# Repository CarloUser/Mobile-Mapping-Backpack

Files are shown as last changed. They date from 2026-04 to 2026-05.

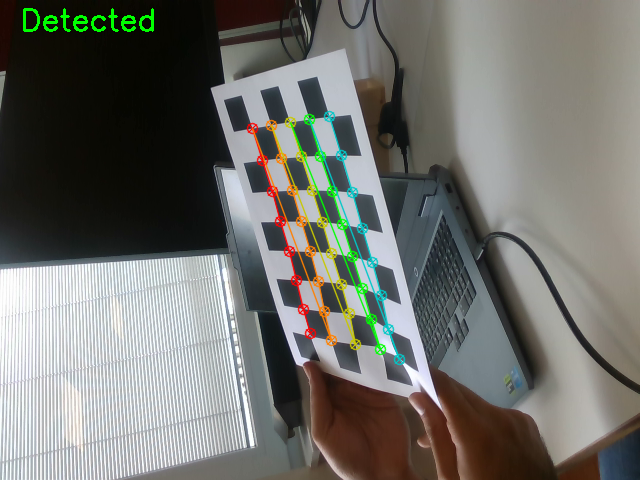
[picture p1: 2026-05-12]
opencv/calib_images/img_28.png

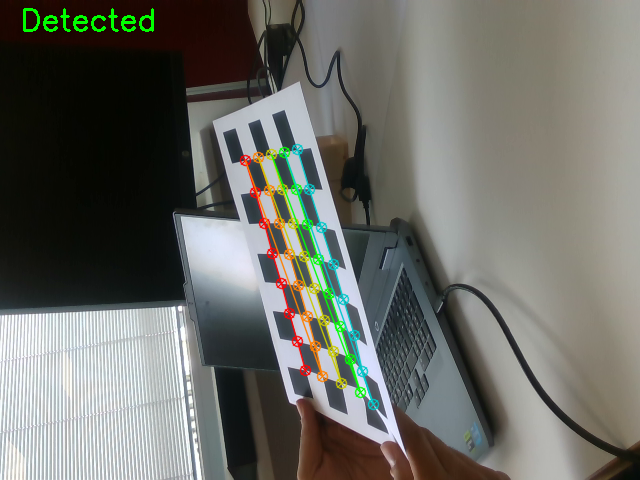
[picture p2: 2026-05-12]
opencv/calib_images/img_25.png

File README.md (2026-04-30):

# Mobile Mapping Backpack

Multi-sensor data acquisition platform integrating LiDAR, cameras, IMU, and GNSS.
Built on ROS2 Humble. Goal: synchronized, time-stamped rosbag recordings for
offline calibration validation and trajectory evaluation.

## Sensor Configuration

| Sensor | Type | Interface | ROS2 Driver |
|---|---|---|---|
| HESAI JT128 | 128-beam LiDAR | GbE | `hesai_ros_driver` |
| OAK-4D Luxonis | RGB-D + IMU | USB3 | `depthai_ros_driver` (v3) |
| OAK-D Lite Luxonis | RGB-D | USB3 | `depthai_ros_driver` |
| Intel RealSense D4xx | RGB-D | USB3 | `realsense2_camera` |
| Xsens MTi-610R | IMU | USB/RS-422 | `xsens_mti_ros2_driver` |
| u-blox + ANN-MB-00 | GNSS/RTK | USB/UART | `ublox_gps` |
| Insta360 | 360° video | Internal SD | *(no ROS2 driver — sync post-hoc)* |

## Compute

| Device | Role |
|---|---|
| NVIDIA Jetson Orin Nano S | Primary ROS2 host — runs all drivers and rosbag2 recording |
| Raspberry Pi | Auxiliary — serial bridge for IMU/GNSS if needed |

## Repository Structure

```
docs/
  setup/
    01_ros2_humble.md       ROS2 Humble installation on Jetson (Ubuntu 22.04)
    02_sensor_drivers.md    Per-sensor driver build and udev rules
    03_time_sync.md         Chrony + PTP time synchronization
  data_collection_protocol.md   Week 1 deliverable — frame IDs, topic names, recording procedure

ros2_ws/src/mmb_bringup/
  launch/
    all_sensors.launch.py   Master launch — brings up every sensor driver
    lidar.launch.py
    cameras.launch.py
    imu_gnss.launch.py
    recording.launch.py     Starts rosbag2 with MCAP storage
  config/
    hesai_jt128.yaml        Hesai driver parameters
    topics.yaml             Topic list for recording

evaluation/
  evo_workflow.md           ATE/RPE evaluation with the evo toolkit
```

## Quick Start

```bash
# 1. Check Ubuntu version — must be 22.04 for Humble
lsb_release -a

# 2. Install ROS2 Humble
# Follow docs/setup/01_ros2_humble.md

# 3. Install sensor drivers
# Follow docs/setup/02_sensor_drivers.md

# 4. Build the bringup package
cd ros2_ws && colcon build --symlink-install
source install/setup.bash

# 5. Launch all sensors
ros2 launch mmb_bringup all_sensors.launch.py

# 6. Start recording (separate terminal)
ros2 launch mmb_bringup recording.launch.py bag_name:=mmb_20260101_1200_hallway_run01
```

## Team

| Student | Role |
|---|---|
| 1 | Camera Calibration Lead |
| 2 | LiDAR Calibration Lead |
| 3 | GNSS-IMU Calibration Lead |
| 4 | Extrinsic Calibration Integrator |
| 5 | CAD Design Lead |
| 6 | System Integration & Testing Lead |

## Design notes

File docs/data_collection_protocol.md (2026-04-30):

# Data Collection Protocol

**Version**: 1.0  
**Owner**: Student 6 — System Integration & Testing Lead  
**Status**: Draft (circulate to team by end of Week 1 for review)

This document defines the naming conventions, frame IDs, topic structure,
recording procedure, and calibration sequences that all team members must
follow to ensure rosbags are interoperable across calibration workflows.

---

## 1. Coordinate Frames and TF Tree

All frames follow the ROS [REP-103](https://www.ros.org/reps/rep-0103.html)
convention: x-forward, y-left, z-up for body frames; ENU for world frames.

```
base_link                    ← physical center of the backpack frame
├── lidar_hesai              ← HESAI JT128 optical center
├── camera_oak4d             ← OAK-4D Luxonis left camera optical center
├── camera_oakd_lite         ← OAK-D Lite left camera optical center
├── camera_realsense         ← Intel RealSense color camera optical center
├── imu_xsens                ← Xsens MTi-610R measurement frame
└── gnss_antenna             ← u-blox ANN-MB-00 antenna phase center
```

**Static transforms** are published at launch from `base_link` to each sensor
frame using estimated poses from Student 5's CAD model. These are placeholders
until Student 4 delivers calibrated extrinsics; update `all_sensors.launch.py`
with the refined values in Week 2.

**Frame IDs used in sensor driver configs**:

| Sensor | `frame_id` |
|---|---|
| HESAI JT128 | `lidar_hesai` |
| OAK-4D (RGB) | `camera_oak4d` |
| OAK-D Lite (RGB) | `camera_oakd_lite` |
| Intel RealSense (color) | `camera_realsense` |
| Xsens MTi-610R | `imu_xsens` |
| u-blox GNSS | `gnss_antenna` |

---

## 2. Topic Naming Convention

All sensor topics live under a sensor-specific namespace:

| Topic | Message Type | Hz (approx) |
|---|---|---|
| `/lidar/points` | `sensor_msgs/PointCloud2` | 10 |
| `/oak4d/rgb/image_raw` | `sensor_msgs/Image` | 30 |
| `/oak4d/depth/image_raw` | `sensor_msgs/Image` | 30 |
| `/oak4d/rgb/camera_info` | `sensor_msgs/CameraInfo` | 30 |
| `/oak4d/imu/data` | `sensor_msgs/Imu` | 500 |
| `/oakd_lite/rgb/image_raw` | `sensor_msgs/Image` | 30 |
| `/oakd_lite/depth/image_raw` | `sensor_msgs/Image` | 30 |
| `/oakd_lite/rgb/camera_info` | `sensor_msgs/CameraInfo` | 30 |
| `/realsense/color/image_raw` | `sensor_msgs/Image` | 30 |
| `/realsense/depth/image_rect_raw` | `sensor_msgs/Image` | 30 |
| `/realsense/color/camera_info` | `sensor_msgs/CameraInfo` | 30 |
| `/imu/data` | `sensor_msgs/Imu` | 400 |
| `/imu/mag` | `sensor_msgs/MagneticField` | 100 |
| `/gnss/fix` | `sensor_msgs/NavSatFix` | 5–10 |
| `/gnss/fix_velocity` | `geometry_msgs/TwistWithCovarianceStamped` | 5–10 |
| `/tf` | `tf2_msgs/TFMessage` | — |
| `/tf_static` | `tf2_msgs/TFMessage` | — |

---

## 3. Bag Naming Convention

```
mmb_YYYYMMDD_HHMM_<location>_<run_type>_<run_number>.mcap
```

Examples:
```
mmb_20260505_1430_lab_calibration_01.mcap
mmb_20260512_1015_hallway_static_01.mcap
mmb_20260518_0930_courtyard_walk_03.mcap
```

**Run types**:
- `calibration` — camera/LiDAR calibration target sequences (static)
- `static` — sensor stationary for IMU noise characterization
- `walk` — normal walking pace, straight or looped path
- `loop` — closed loop for drift evaluation

Store bags on an **NVMe SSD** mounted at `/data/bags/`. Multi-sensor recording
at full rate produces ~1.5–2 GB/min. A 500 GB SSD gives roughly 4 hours of
recording time.

---

## 4. Recording Procedure

### 4.1 Pre-run Checklist

- [ ] Jetson booted, time sync confirmed (`chronyc tracking` shows < 2 ms offset)
- [ ] All sensors powered and publishing (`ros2 topic list` shows all topics)
- [ ] Storage has sufficient space (`df -h /data`)
- [ ] Topic rates verified (`ros2 topic hz /lidar/points`, etc.)
- [ ] Insta360 internal recording started and timestamp noted

### 4.2 Start Recording

```bash
# Terminal 1 — launch all sensor drivers
ros2 launch mmb_bringup all_sensors.launch.py

# Terminal 2 — start recording (replace bag name as appropriate)
ros2 launch mmb_bringup recording.launch.py \
  bag_name:=/data/bags/mmb_20260505_1430_lab_calibration_01
```

### 4.3 During Recording

- Keep the backpack as still as possible for the first **10 seconds** to
  establish a clean IMU static baseline.
- For outdoor runs, wait for GNSS fix confirmation before starting motion
  (`ros2 topic echo /gnss/fix --once` should show `status.status >= 0`).
- Note the Insta360 start timestamp in the run log (see Section 6).

### 4.4 Stop Recording

```bash
# Ctrl+C in Terminal 2 to stop rosbag2
# Verify the bag is not corrupted
ros2 bag info /data/bags/mmb_20260505_1430_lab_calibration_01
```

---

## 5. Calibration Data Sequences

The following sequences must be captured before Week 2 to give Students 1–4
the data they need.

### 5.1 Camera Intrinsics (Student 1)

- Use a **7×10 chessboard** (square size 30 mm).
- Record ~60–80 frames with the board in varied positions and orientations.
- Cover all corners of the image frame and include tilted views.
- Bag type: `calibration`, camera stationary or hand-held board.

```bash
# Record cameras only for efficiency during intrinsics
ros2 bag record -o /data/bags/mmb_20260505_1000_lab_calibration_intrinsics \
  --storage mcap \
  /oak4d/rgb/image_raw /oak4d/rgb/camera_info \
  /oakd_lite/rgb/image_raw /oakd_lite/rgb/camera_info \
  /realsense/color/image_raw /realsense/color/camera_info
```

### 5.2 LiDAR Calibration (Student 2)

- Use a **flat planar target** (e.g., a large foam board) at various distances (1–5 m).
- Hold the board stationary for 3–5 seconds per position.
- Capture at least 10 positions covering different depths and angles.

### 5.3 IMU Static Calibration (Student 3)

- Place the backpack completely still on a flat surface.
- Record **at least 30 minutes** of static IMU data for Allan Variance analysis.

```bash
ros2 bag record -o /data/bags/mmb_20260505_1100_lab_static_imu \
  --storage mcap /imu/data /imu/mag
```

### 5.4 Extrinsic Calibration (Student 4)

- Print and mount **AprilTag board** (tagStandard41h12, 10 cm tags).
- Record all cameras and LiDAR simultaneously viewing the board from multiple angles.
- Walk slowly around the board, pausing at each angle.

---

## 6. Run Log

Maintain a physical or shared-document log for every recording session.
Minimum entries per run:

| Field | Example |
|---|---|
| Date/Time | 2026-05-05 14:30 |
| Bag name | mmb_20260505_1430_lab_calibration_01 |
| Location | Lab room 203 |
| Operators | Student 6, Student 1 |
| Insta360 start time | 14:31:05 UTC |
| Weather (outdoor) | Overcast, dry |
| GNSS fix type (outdoor) | RTK Fixed |
| Notes | Board illumination uneven — retake positions 4–6 |

---

## 7. Quality Checks After Each Session

```bash
# Check bag integrity and duration
ros2 bag info /data/bags/<bag_name>

# Spot-check topic rates in the bag
ros2 bag play /data/bags/<bag_name> --clock &
ros2 topic hz /lidar/points
ros2 topic hz /imu/data

# Check for timestamp jumps or gaps (>100 ms gap on any topic is a problem)
# Use evo_traj or a simple Python script to plot timestamps
```

If any topic is missing or the rate is consistently less than 50% of expected,
re-record before moving on.

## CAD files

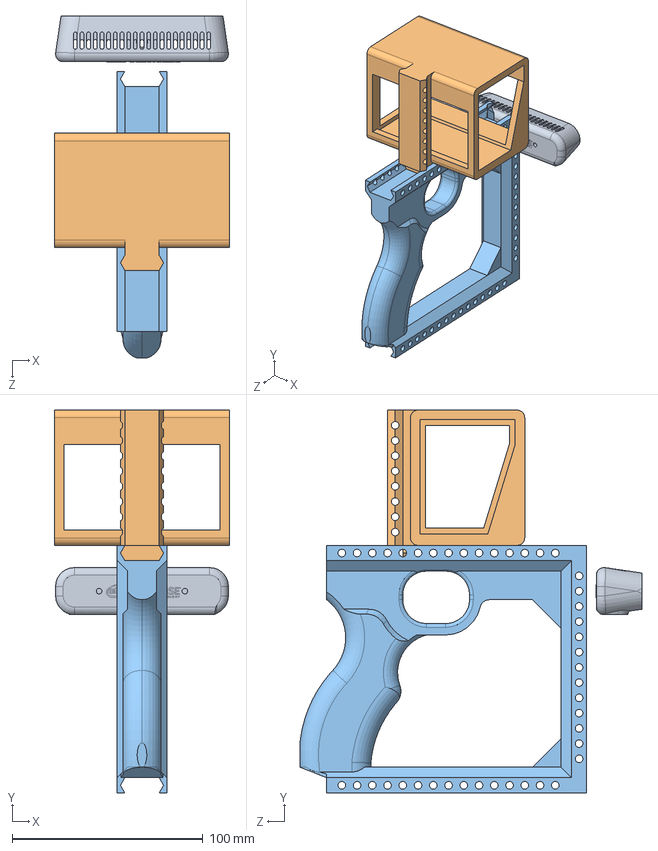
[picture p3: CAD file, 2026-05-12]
cad/Handheld/V4/Assembly_V4.SLDASM
92.0 x 200.9 x 179.4 mm
Grip_V4
Cube_Mount
RealSense_D435

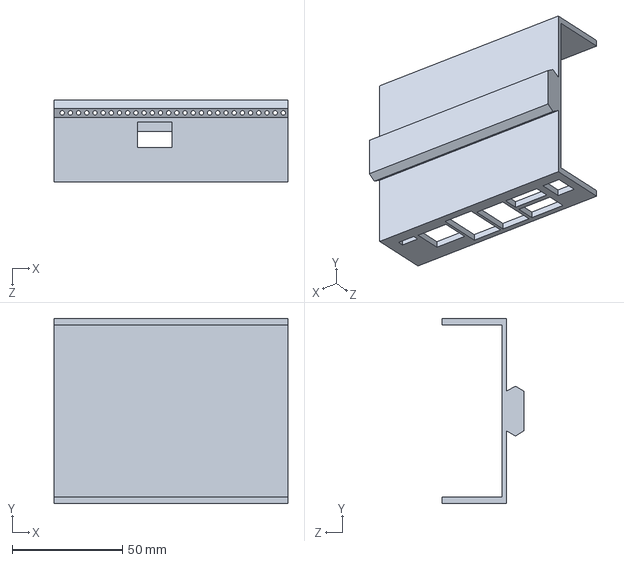
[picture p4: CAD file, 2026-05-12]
cad/Handheld/Board_Mounts/JetsonMount.SLDPRT
106.0 x 84.0 x 36.9 mm

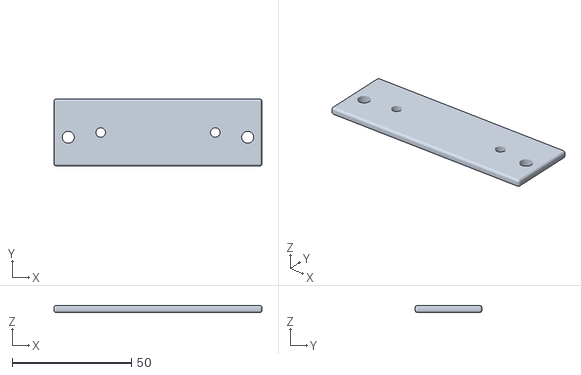
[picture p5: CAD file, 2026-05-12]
cad/Handheld/V3_STL/OAK_D_Lite_Mount.STL
87.1 x 28.0 x 3.00

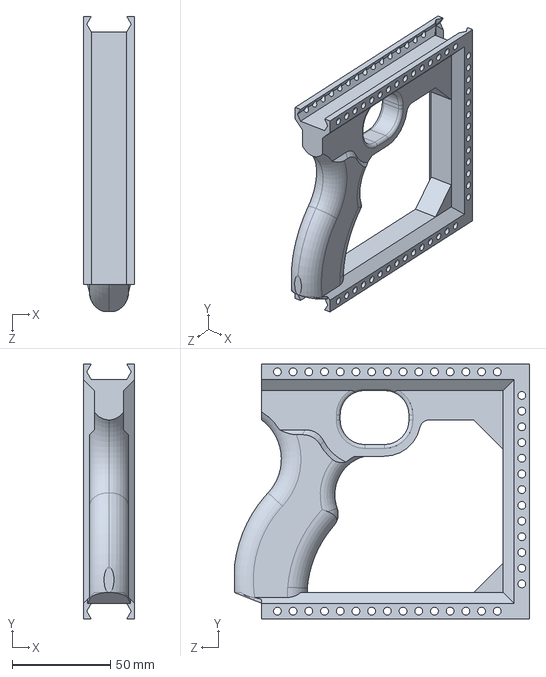
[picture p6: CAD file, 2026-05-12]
cad/Handheld/V4/Grip_V4.SLDPRT
26.0 x 129.9 x 150.4 mm

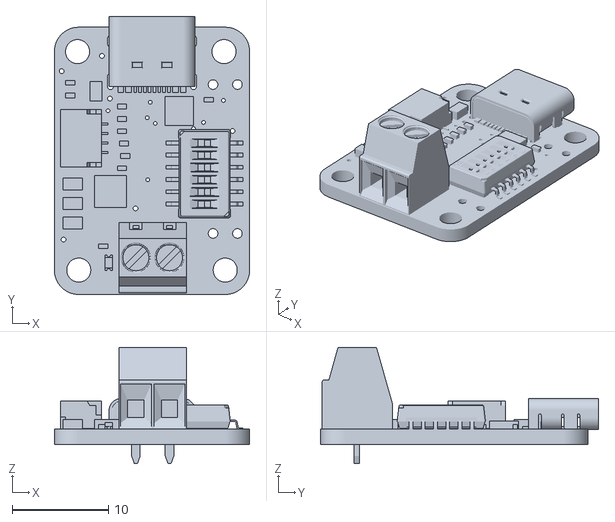
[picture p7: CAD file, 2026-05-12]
cad/Sources/Adafruit/5991 HUSB238 USBC.stl
20.3 x 28.9 x 12.1

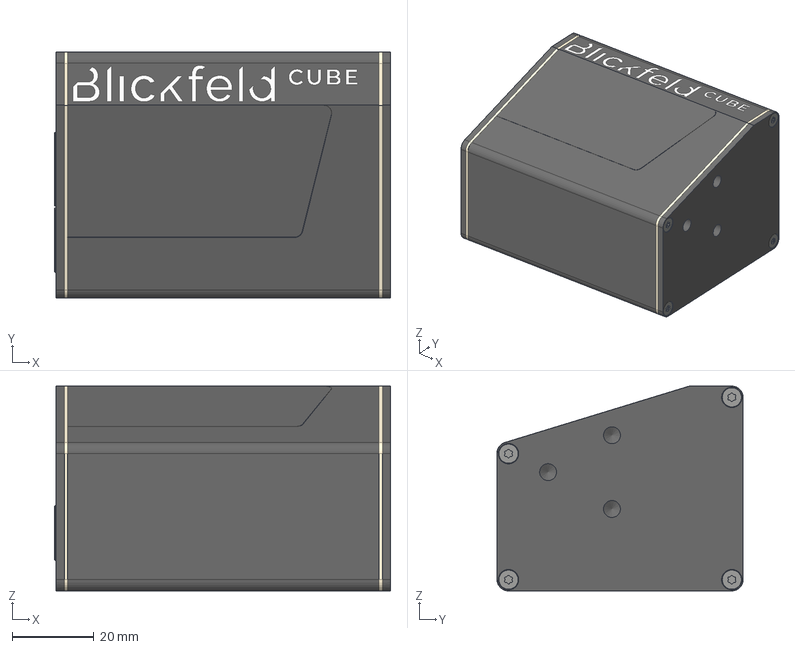
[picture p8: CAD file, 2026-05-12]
cad/Sources/Blickfeld/Cube 1.stp
82.0 x 60.1 x 50.0 mm

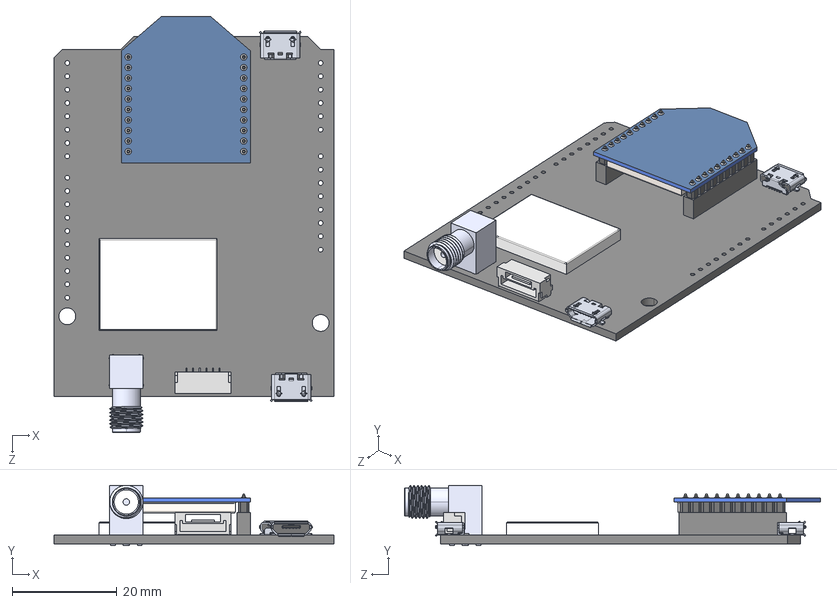
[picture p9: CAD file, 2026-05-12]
cad/Sources/GNSS/simpleRTK2B_Budget.STEP
53.3 x 11.5 x 79.3 mm
simpleRTK2B_PCB
micro_usb x 2
Pixhawk_connector
GNSS_SMA
User Library-XBee-Chip_XBee-10pin-male_1 x 2
User Library-XBee-Chip_XBee-Chip_1
ZED-F9P

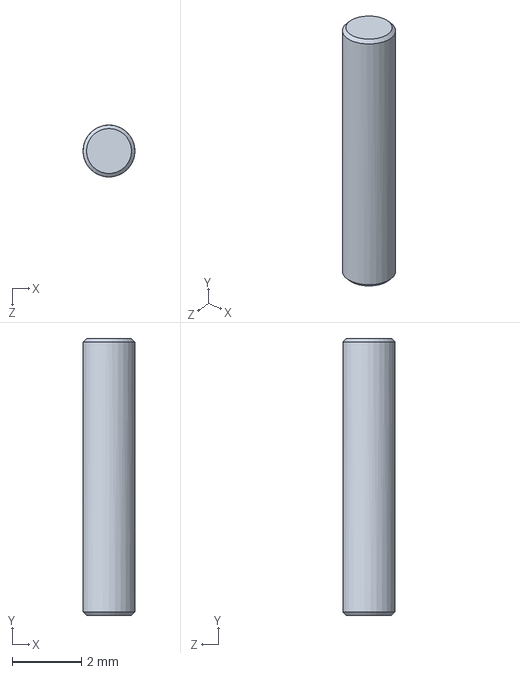
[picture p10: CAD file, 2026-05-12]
cad/Sources/Grips/Slingshot Rifle Part-20.SLDPRT
1.50 x 8.00 x 1.50 mm

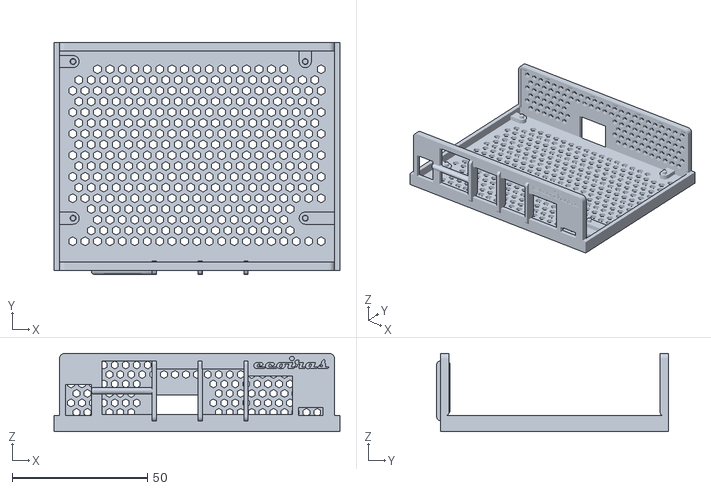
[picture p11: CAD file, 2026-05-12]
cad/Sources/JetsonCase/NanoBox_Bottom_v21.stl
105.9 x 85.8 x 29.0

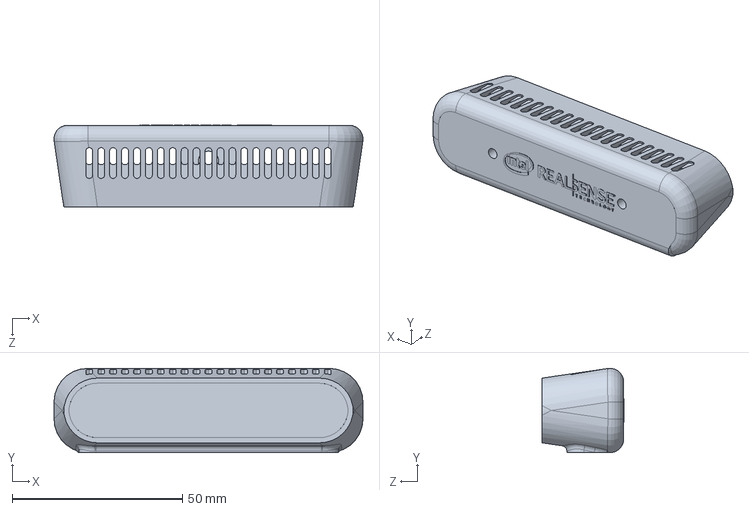
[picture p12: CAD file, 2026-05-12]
cad/Sources/RealSense/RealSense_D435.SLDPRT
90.7 x 24.7 x 24.1 mm

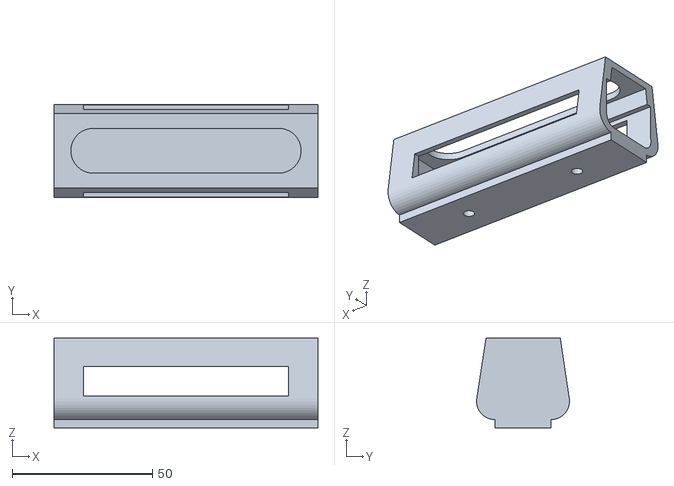
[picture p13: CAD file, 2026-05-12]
cad/Handheld/V3_STL/RealSenseMount_V3.STL
94.0 x 33.1 x 32.0

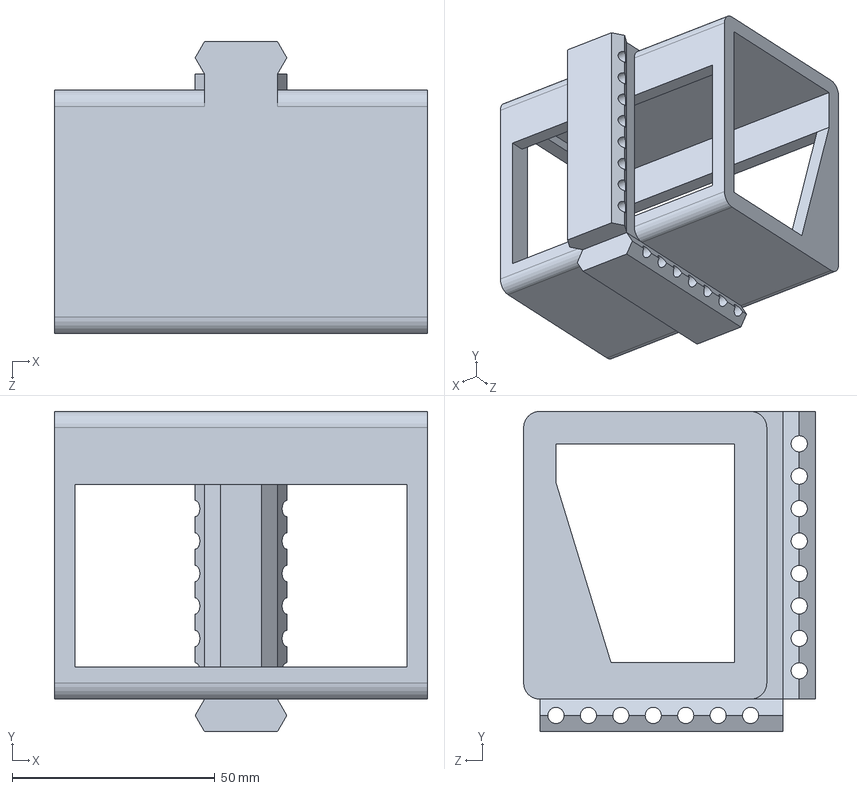
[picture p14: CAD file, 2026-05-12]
cad/Handheld/V4/Cube_Mount.SLDPRT
92.0 x 79.0 x 72.0 mm

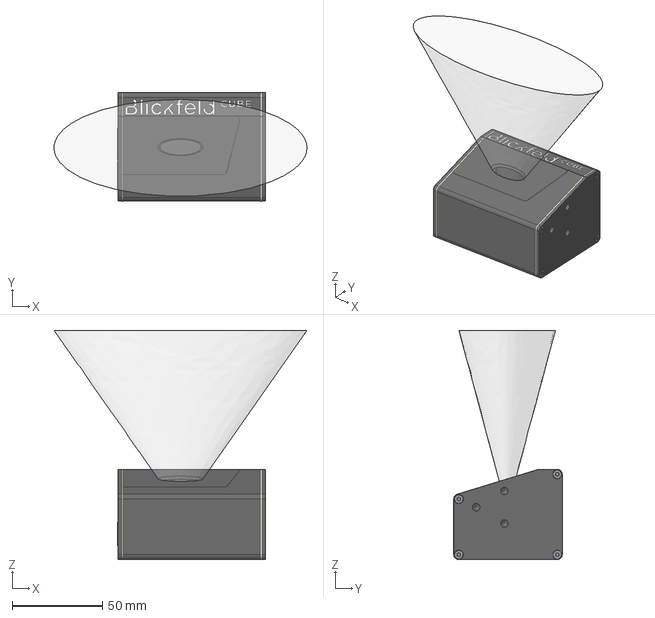
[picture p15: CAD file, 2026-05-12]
cad/Sources/Blickfeld/Cube 1-FieldofView.stp
140.0 x 60.1 x 126.9 mm

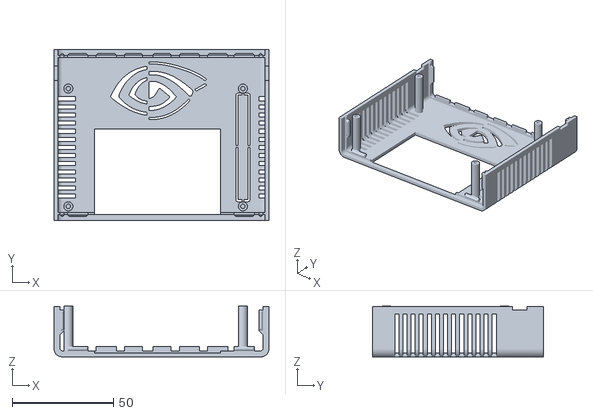
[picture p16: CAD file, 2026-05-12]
cad/Sources/JetsonCase/NanoBox_Top_v22.stl
105.9 x 84.3 x 25.0

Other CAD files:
cad/Sources/Grips/Heavy-Duty Slingshot Rifle.SLDASM
cad/Sources/Grips/Trigger-Asy.SLDASM
cad/Handheld/Board_Mounts/PI_Mount.SLDPRT
cad/Handheld/V3_STL/Rail_Bottom_V3.STL
cad/Handheld/V3/Assembly_V3.SLDASM
cad/Handheld/V3/Grip/Connector_V3.SLDPRT
cad/Handheld/V3/Grip/DirectMount_V3.SLDPRT
cad/Handheld/V3/Grip/Grip_V3.SLDPRT
cad/Handheld/V3/Grip/Mount_V3.SLDPRT
cad/Handheld/V3/Grip/Old Versions/BaseGrip_Slingshot_V1.SLDPRT
cad/Handheld/V3/Grip/Old Versions/BaseGrip_Slingshot_V2.SLDPRT
cad/Handheld/V3/Grip/Old Versions/BaseGrip_Slingshot_V2.STL
cad/Handheld/V3/Grip/Old Versions/BaseGrip_Slingshot_V2_Hollow.SLDPRT
cad/Handheld/V3/Grip/Old Versions/Cube1_BoundingBox.STL
cad/Handheld/V3/Grip/Old Versions/Grip_Assembly.SLDASM
cad/Handheld/V3/Grip/Old Versions/Grip_V2_Assembly.SLDASM
cad/Handheld/V3/Grip/Old Versions/LowerAttachement_Bare.SLDPRT
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

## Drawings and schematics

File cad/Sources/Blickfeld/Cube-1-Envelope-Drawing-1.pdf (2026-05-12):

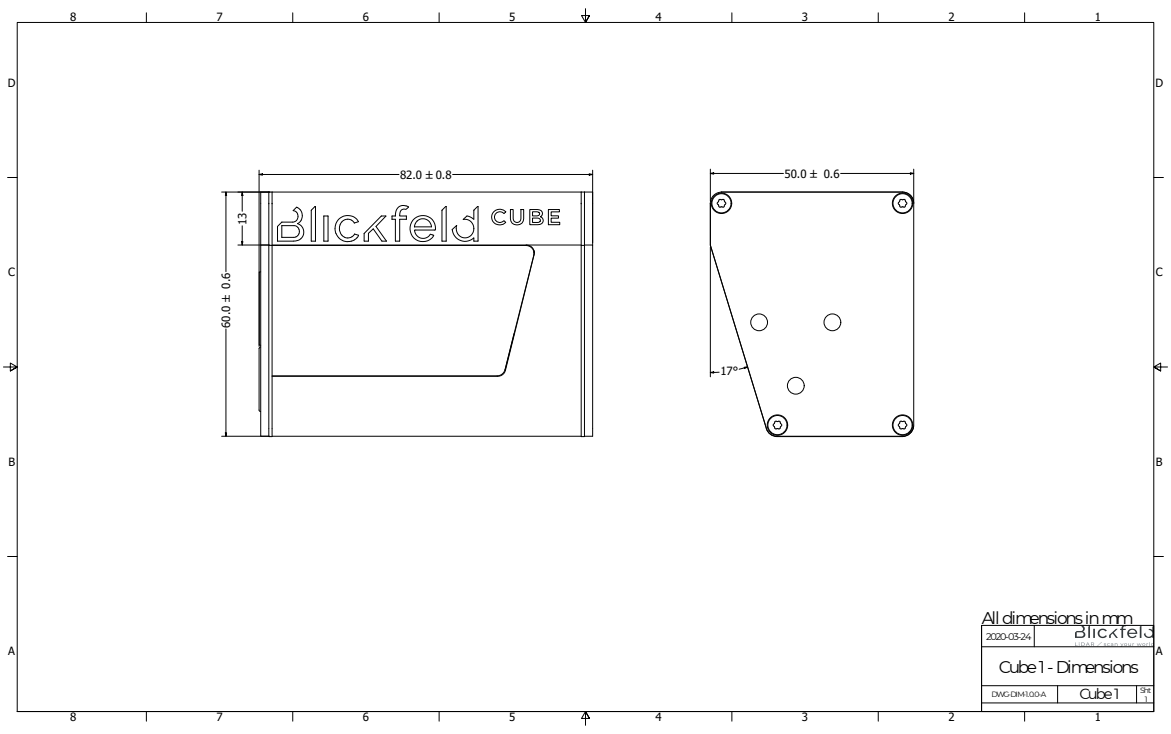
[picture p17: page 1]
Alldimensionsinmm; Cube1-Dimensions; DWG-DIM-1.0.0-A; Sht Cube1

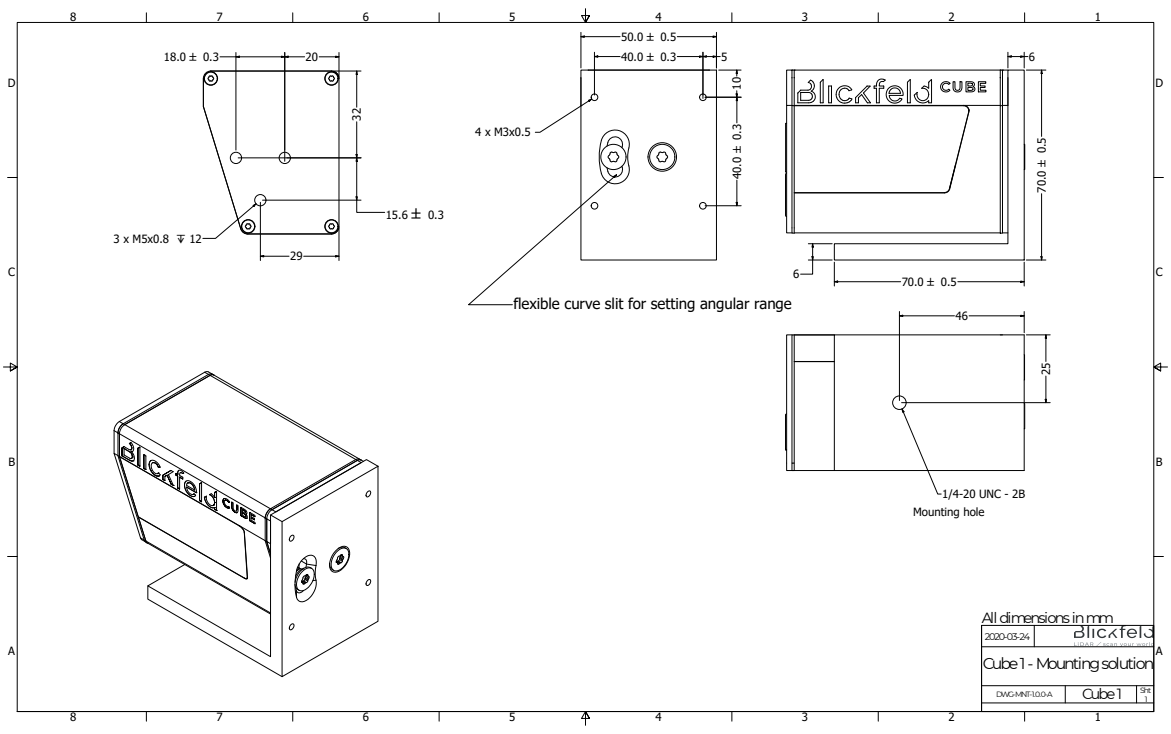
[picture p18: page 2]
Mounting hole; Alldimensionsinmm; Cube1-Mountingsolution; DWG-MNT-1.0.0-A; Sht Cube; 1/4-20 UNC - 2B

flexible curve slit for setting angular range

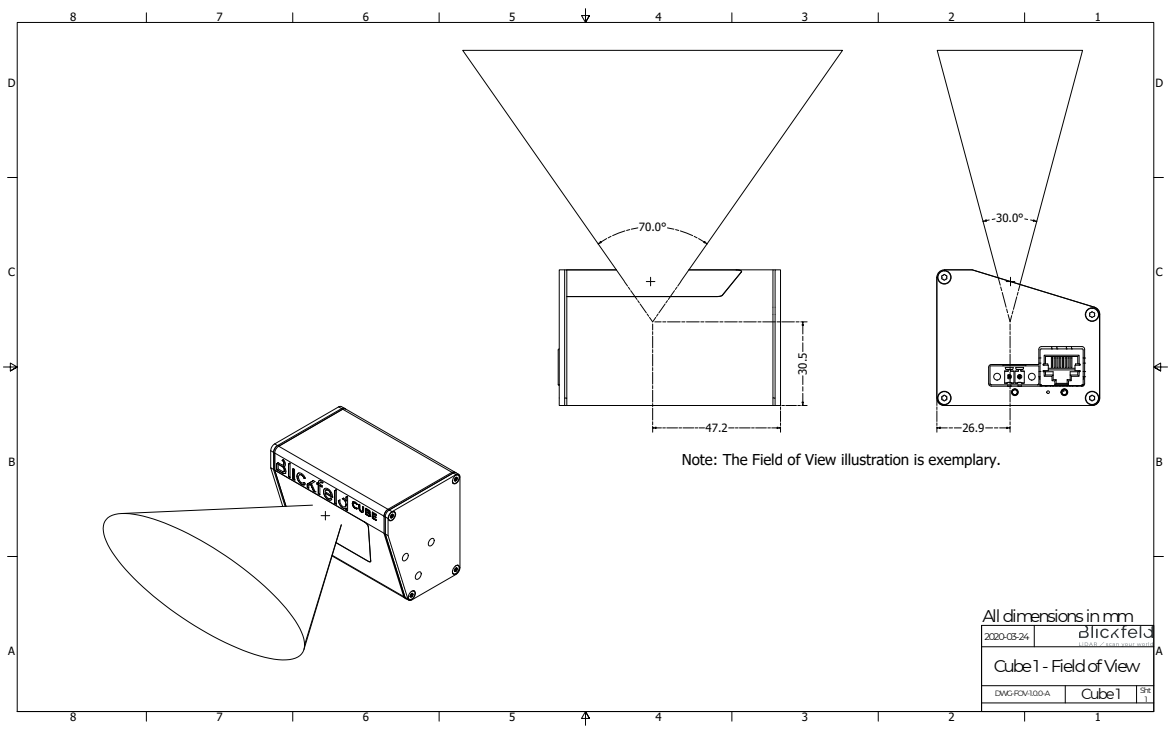
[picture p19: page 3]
Alldimensionsinmm; Cube1-FieldofView; DWG-FOV-1.0.0-A; Sht Cube

Note: The Field of View illustration is exemplary.

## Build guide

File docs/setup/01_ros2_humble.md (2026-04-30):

# ROS2 Humble Installation (Jetson Orin Nano S — Ubuntu 22.04)

## Prerequisites

ROS2 Humble requires **Ubuntu 22.04**. Verify before proceeding:

```bash
lsb_release -a
# Must show: Ubuntu 22.04.x LTS
```

If the Jetson is running JetPack 5.x (Ubuntu 20.04), you need to reflash with
JetPack 6.x first. Download SDK Manager from NVIDIA and flash via USB-C.

---

## 1. Set Locale

```bash
sudo apt update && sudo apt install -y locales
sudo locale-gen en_US en_US.UTF-8
sudo update-locale LC_ALL=en_US.UTF-8 LANG=en_US.UTF-8
export LANG=en_US.UTF-8
```

## 2. Add ROS2 Apt Repository

```bash
sudo apt install -y software-properties-common curl
sudo curl -sSL https://raw.githubusercontent.com/ros/rosdistro/master/ros.key \
  -o /usr/share/keyrings/ros-archive-keyring.gpg

echo "deb [arch=$(dpkg --print-architecture) signed-by=/usr/share/keyrings/ros-archive-keyring.gpg] \
  http://packages.ros.org/ros2/ubuntu $(. /etc/os-release && echo $UBUNTU_CODENAME) main" \
  | sudo tee /etc/apt/sources.list.d/ros2.list > /dev/null

sudo apt update
```

## 3. Install ROS2 Humble

```bash
sudo apt install -y ros-humble-desktop
```

## 4. Install Build Tools

```bash
sudo apt install -y python3-colcon-common-extensions python3-rosdep python3-pip
sudo rosdep init
rosdep update
```

## 5. Install MCAP Storage Plugin

rosbag2 defaults to SQLite3, which is slow for high-rate sensors. MCAP is
required for reliable multi-sensor recording.

```bash
sudo apt install -y ros-humble-rosbag2-storage-mcap
```

## 6. Shell Setup

```bash
echo "source /opt/ros/humble/setup.bash" >> ~/.bashrc
source ~/.bashrc
```

## 7. Verify

```bash
ros2 doctor
# Should report no critical issues
ros2 bag record --help | grep mcap
# Should show mcap as an available storage plugin
```

---

## Next Step

→ [02_sensor_drivers.md](02_sensor_drivers.md) — install drivers for each sensor.

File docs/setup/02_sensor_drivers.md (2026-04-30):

# Sensor Driver Installation

Install and verify each driver individually before combining in the full launch.
All builds go into `~/ros2_ws` unless noted otherwise.

```bash
mkdir -p ~/ros2_ws/src
cd ~/ros2_ws
```

---

## HESAI JT128 LiDAR

**Interface**: Ethernet (GbE). Default LiDAR IP: `192.168.1.201`.
Set the Jetson's Ethernet interface to a static IP in the same subnet, e.g. `192.168.1.100`.

```bash
cd ~/ros2_ws/src
git clone https://github.com/HesaiTechnology/HesaiLidar_ROS_2.0.git --recursive

cd ~/ros2_ws
rosdep install --from-paths src --ignore-src -r -y
colcon build --symlink-install --packages-select hesai_ros_driver
source install/setup.bash
```

**Verify** (LiDAR powered and connected):
```bash
ros2 launch hesai_ros_driver start.py
# In another terminal:
ros2 topic hz /lidar_points
# Should show ~10 Hz (default rotation rate)
```

**Jetson Ethernet static IP setup**:
```bash
# Replace eth0 with your actual interface name (check: ip link)
sudo nmcli con add type ethernet ifname eth0 con-name hesai-lidar \
  ip4 192.168.1.100/24
sudo nmcli con up hesai-lidar
```

---

## OAK-4D Luxonis and OAK-D Lite Luxonis

Both use `depthai-ros`. The OAK-4D uses the v3 API; OAK-D Lite uses v2.
Install udev rules first so USB access works without sudo.

```bash
# udev rules
echo 'SUBSYSTEM=="usb", ATTRS{idVendor}=="03e7", MODE="0666"' \
  | sudo tee /etc/udev/rules.d/80-movidius.rules
sudo udevadm control --reload-rules && sudo udevadm trigger
```

```bash
# ROS2 package (apt — prebuilt for Humble)
sudo apt install -y ros-humble-depthai-ros

# If apt package is outdated, build from source instead:
# cd ~/ros2_ws/src
# git clone https://github.com/luxonis/depthai-ros.git
# cd ~/ros2_ws && colcon build --symlink-install --packages-select depthai_ros_driver
```

**Verify** (camera plugged in via USB3 — use the USB3 port, not USB2):
```bash
# OAK-D Lite
ros2 launch depthai_ros_driver camera.launch.py camera_model:=OAK-D-LITE
ros2 topic hz /oak/rgb/image_raw

# OAK-4D (use camera_model:=OAK-4D or check depthai-ros docs for exact name)
ros2 launch depthai_ros_driver camera.launch.py camera_model:=OAK-4
```

**Note**: If running both OAK cameras simultaneously, each needs a separate
USB3 port (or a powered USB3 hub). They must be launched with different
namespaces — see `cameras.launch.py`.

---

## Intel RealSense

```bash
# librealsense2 via Intel apt repo
sudo apt-key adv --keyserver keyserver.ubuntu.com --recv-key F6E65AC044F831AC
sudo add-apt-repository "deb https://librealsense.intel.com/Debian/apt-repo $(lsb_release -cs) main"
sudo apt update
sudo apt install -y librealsense2-dkms librealsense2-utils librealsense2-dev

# ROS2 wrapper
sudo apt install -y ros-humble-realsense2-camera ros-humble-realsense2-description
```

**Verify**:
```bash
# First check the camera is detected
realsense-viewer  # optional GUI
rs-enumerate-devices

ros2 launch realsense2_camera rs_launch.py
ros2 topic hz /camera/color/image_raw
```

---

## Xsens MTi-610R IMU

**Interface**: USB (shows as `/dev/ttyUSB0` or `/dev/ttyACM0`).

```bash
# udev rule for serial access without sudo
sudo usermod -aG dialout $USER   # log out and back in after this

cd ~/ros2_ws/src
git clone https://github.com/nobleo/xsens_mti_ros2_driver.git
cd ~/ros2_ws
rosdep install --from-paths src --ignore-src -r -y
colcon build --symlink-install --packages-select xsens_mti_ros2_driver
source install/setup.bash
```

**Verify**:
```bash
# Check which port the IMU appears on
ls /dev/ttyUSB* /dev/ttyACM*

ros2 launch xsens_mti_ros2_driver xsens_mti_node.launch.py
ros2 topic hz /imu/data    # should be 400 Hz for MTi-610R
```

**Baud rate**: The MTi-610R defaults to 115200 baud via USB but can go up to
921600. Configure with MT Manager (Windows/Linux) before deployment if needed.

---

## u-blox GNSS (with ANN-MB-00 Antenna)

The ANN-MB-00 is a multi-band antenna — it connects to a u-blox receiver
(e.g., ZED-F9P evaluation board or equivalent). Confirm what receiver board
you have; the antenna alone does not connect to USB.

```bash
sudo apt install -y ros-humble-ublox
# Or build from source for more recent fixes:
# cd ~/ros2_ws/src
# git clone https://github.com/KumarRobotics/ublox.git -b ros2
# colcon build --symlink-install --packages-select ublox_gps
```

**Verify**:
```bash
# Check serial port
ls /dev/ttyUSB* /dev/ttyACM*

ros2 run ublox_gps ublox_gps_node --ros-args \
  -p device:=/dev/ttyACM0 \
  -p frame_id:=gnss \
  -p config_on_startup:=false

ros2 topic echo /fix     # NavSatFix messages once outdoors with sky view
```

---

## Insta360 (360° Camera)

There is no ROS2 driver for the Insta360. Use this workflow instead:

1. **Record internally** to the Insta360's SD card during each run.
2. **Sync timestamps** post-hoc using the GPS track in the rosbag to align
   the Insta360 footage via GPS-embedded metadata or a visible event
   (e.g., a flash LED triggered at recording start).
3. Export frames with `ffmpeg` if needed for offline processing.

No driver installation required.

---

## Build Everything Together

After cloning all source-built packages:

```bash
cd ~/ros2_ws
rosdep install --from-paths src --ignore-src -r -y
colcon build --symlink-install
source install/setup.bash
```

Add workspace to `.bashrc` so it persists:
```bash
echo "source ~/ros2_ws/install/setup.bash" >> ~/.bashrc
```

---

## Next Step

→ [03_time_sync.md](03_time_sync.md) — configure time synchronization before
doing any multi-sensor recording.

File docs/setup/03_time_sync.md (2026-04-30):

# Time Synchronization

Misaligned timestamps corrupt calibration and make trajectory evaluation
unreliable. Target: all sensor timestamps agree to within ~1 ms for
indoor tests, <0.1 ms for outdoor RTK evaluation.

Two layers apply here:

1. **System clock sync** (chrony/NTP) — keeps the Jetson's Linux clock aligned
   to UTC. Affects all sensors that stamp using `ros::Time::now()`.
2. **LiDAR hardware sync** (PTP) — the HESAI JT128 has an internal clock that
   can be disciplined via IEEE 1588 PTP, giving it sub-millisecond alignment
   independent of the CPU.

---

## 1. Install and Configure Chrony

```bash
sudo apt install -y chrony
```

Edit `/etc/chrony/chrony.conf`. Replace the default pool lines with:

```
# Use pool.ntp.org when internet is available
pool pool.ntp.org iburst maxsources 4

# Fall back to the Jetson's own clock when offline (important for field use)
local stratum 10

# Allow ROS nodes on the same LAN to use this Jetson as NTP server
allow 192.168.0.0/16
```

```bash
sudo systemctl restart chrony
# Check sync status (wait ~30 s after restart)
chronyc tracking
# "System time" should drop to <1 ms within a minute on a good internet connection
```

---

## 2. HESAI JT128 PTP Synchronization

The JT128 can act as a **PTP slave**, disciplining its internal clock to a
PTP master on the network. The Jetson can serve as the master using `linuxptp`.

```bash
sudo apt install -y linuxptp
```

Identify the Ethernet interface connected to the LiDAR:
```bash
ip link   # e.g., eth0 or enp3s0
```

Start `ptp4l` as master on that interface:
```bash
sudo ptp4l -i eth0 -m -s    # -m = master, -s = software timestamping
# For hardware timestamping (preferred if NIC supports it):
sudo ptp4l -i eth0 -m -H
```

Sync the system clock to PTP time:
```bash
sudo phc2sys -a -rr -s CLOCK_REALTIME -m
```

**Configure the LiDAR**: Open the JT128 web interface at `http://192.168.1.201`,
navigate to **Network → PTP** and enable PTP slave mode. After ~30 seconds,
the LiDAR's internal clock should track the Jetson's PTP master.

**Verify** in the JT128 web UI: PTP status should show "Locked" or check the
`lidar_points` PointCloud2 header timestamps against `ros2 topic echo /clock`.

---

## 3. IMU and Camera Timestamps

The Xsens MTi-610R, OAK cameras, and RealSense all stamp using the host system
clock via their USB drivers. With chrony keeping the Jetson clock accurate,
these are automatically aligned. No extra configuration needed.

**Exception**: The OAK-4D has an onboard IMU that can optionally use hardware
timestamps. Check the depthai-ros `imu_from_descr` parameter — leaving it
at the default (software timestamps) is acceptable for our purposes.

---

## 4. Verify End-to-End

With all sensors running:

```bash
# Check timestamp spread across all sensor topics
ros2 topic echo /lidar_points --field header.stamp --once
ros2 topic echo /imu/data --field header.stamp --once
ros2 topic echo /oak4d/rgb/image_raw --field header.stamp --once
```

All stamps should be within a few milliseconds of each other. Large
discrepancies (>50 ms) indicate a driver not using the system clock or a
chrony sync issue.

```bash
# Quick sanity check
chronyc tracking | grep "System time"
```

---

## Field Operation Note

When operating outdoors with GNSS, the u-blox receiver outputs a **1 PPS signal**
on its timepulse pin. For maximum accuracy, this PPS can be fed into the
Jetson's GPIO and used to discipline chrony at the hardware level
(`refclock SHM 0 refid GPS`). This provides UTC-aligned accuracy < 1 μs.
This is optional for the current project scope but worth noting for future
improvement.

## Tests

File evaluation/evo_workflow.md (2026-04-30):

# Trajectory Evaluation with evo

For Week 4 evaluation against RTK GNSS ground truth.
The `evo` toolkit reads ROS2 bags directly and computes ATE and RPE.

## Installation

```bash
pip install evo --upgrade
```

## Concepts

- **ATE (Absolute Trajectory Error)**: root-mean-square distance between
  estimated and ground-truth poses after optimal alignment. Global accuracy.
- **RPE (Relative Pose Error)**: pose drift over fixed time or distance windows.
  Local/incremental accuracy — better reflects what you'd see during a walk.

---

## Workflow

### Step 1 — Prepare Ground Truth

The RTK GNSS trajectory from `/gnss/fix` (NavSatFix messages) must be
converted to a TUM-format file or kept as a ROS2 bag topic.

The `evo` toolkit can read NavSatFix directly from a ROS2 bag if you convert
it to a path first. Use this helper script:

```bash
# Convert NavSatFix bag to TUM trajectory file
# (LLH → local ENU, origin = first fix)
python3 evaluation/navsat_to_tum.py \
  --bag /data/bags/mmb_20260518_0930_courtyard_walk_01 \
  --topic /gnss/fix \
  --output /data/bags/ground_truth_walk_01.tum
```

*(See `evaluation/navsat_to_tum.py` — to be created after GNSS integration is complete.)*

### Step 2 — Extract Estimated Trajectory

If you ran a SLAM or odometry stack on the bag, its output is typically a
`nav_msgs/Odometry` or `geometry_msgs/PoseStamped` topic. Extract it:

```bash
evo_traj bag2 /data/bags/mmb_20260518_0930_courtyard_walk_01 \
  /odom --save_as_tum -o /data/bags/estimated_walk_01.tum
```

### Step 3 — Compute ATE

```bash
evo_ape tum \
  /data/bags/ground_truth_walk_01.tum \
  /data/bags/estimated_walk_01.tum \
  --align --correct_scale \
  --plot --plot_mode xy \
  --save_results /data/results/ape_walk_01.zip
```

### Step 4 — Compute RPE

```bash
evo_rpe tum \
  /data/bags/ground_truth_walk_01.tum \
  /data/bags/estimated_walk_01.tum \
  --align --delta 1 --delta_unit m \
  --plot --plot_mode xy \
  --save_results /data/results/rpe_walk_01.zip
```

### Step 5 — Compare Multiple Runs

```bash
evo_res /data/results/*.zip --use_filenames --save_table results_summary.csv
```

---

## Sanity Checks Before Running evo

```bash
# Verify both trajectories have overlapping timestamps
evo_traj tum ground_truth_walk_01.tum estimated_walk_01.tum --plot

# The two tracks should overlap spatially after alignment.
# If they don't, check:
#   1. Timestamp units (evo expects seconds, not nanoseconds)
#   2. Coordinate frame consistency (both must be in the same world frame)
#   3. Time sync — was chrony running during the recording?
```

---

## Reporting Metrics

Report both ATE and RPE for each test run. Typical acceptable values for
a walking-speed backpack system:

| Metric | Good | Acceptable |
|---|---|---|
| ATE RMSE | < 0.1 m | < 0.5 m |
| RPE (1 m window) | < 0.05 m | < 0.2 m |

These thresholds depend heavily on which estimation pipeline is used.
Document the pipeline version alongside every result.

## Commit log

2026-04-30 Initialize project structure for Student 6 (System Integration & Testing Lead)
    - README with sensor table, compute roles, and repo map
    - docs/setup: ROS2 Humble install, per-sensor driver guide, time sync (chrony + PTP)
    - docs/data_collection_protocol.md: Week 1 deliverable — frame IDs, topic
    naming, bag naming convention, recording procedure, calibration sequences,
    and post-run quality checks
    - ros2_ws/src/mmb_bringup: ROS2 bringup package with launch files for each
    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
2026-05-12 Added-CAD-files from previous iterations
    [5991 HUSB238 USBC.stl, Adafruit_Mount.SLDPRT, Assembly_V3.SLDASM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]
